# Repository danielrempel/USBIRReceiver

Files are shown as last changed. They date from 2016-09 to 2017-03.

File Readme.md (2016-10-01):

USBIRReceiver — an Atmega8L-based USB device to receive IR NEC commands from remote
control and configurable host software to run commands upon receiving
configured codes.

Device firmware is using Objective Development's V-USB (https://www.obdev.at/vusb/).
Host software uses Ben Hoyt's 'inih' library (https://github.com/benhoyt/inih).

Host software launches commands from its configuration file so it is
important to run the program from ordinary user. The user will need
rights to access the usb device.
I expect that adding a udev rule like this one:
> SUBSYSTEM=="usb", ATTR{idVendor}=="16c0", ATTR{idProduct}=="05dc", GROUP==<group>, MODE="0666"
will be enough.

Building:
* put usbdrv folder from OBdev's V-USB to the firmware folder without
	replacing the usbconfig.h file
* put Ben Hoyt's 'inih' library souces (ini.c,ini.h) to <project-root>/inih/
* firmware: cd firmware; make; make flash [; make fuse -- in case you need to re-fuse]
* host-side: cd host-side; make

NOTE: firmware's Makefile is configured to work with avrdude & USBAsp

NOTE: commands in ini file must not contain quoted spaces, up to 20 args

NOTE: repeat cmd from IR NEC is sent as 0xFA/0xFA by the receiver
		according to the standard it may be sent 104ms after the initial press
		from my experience it's not enough, so I just did code any reaction to it
		(on my remote a single click is constantly treated as a click + repeat)

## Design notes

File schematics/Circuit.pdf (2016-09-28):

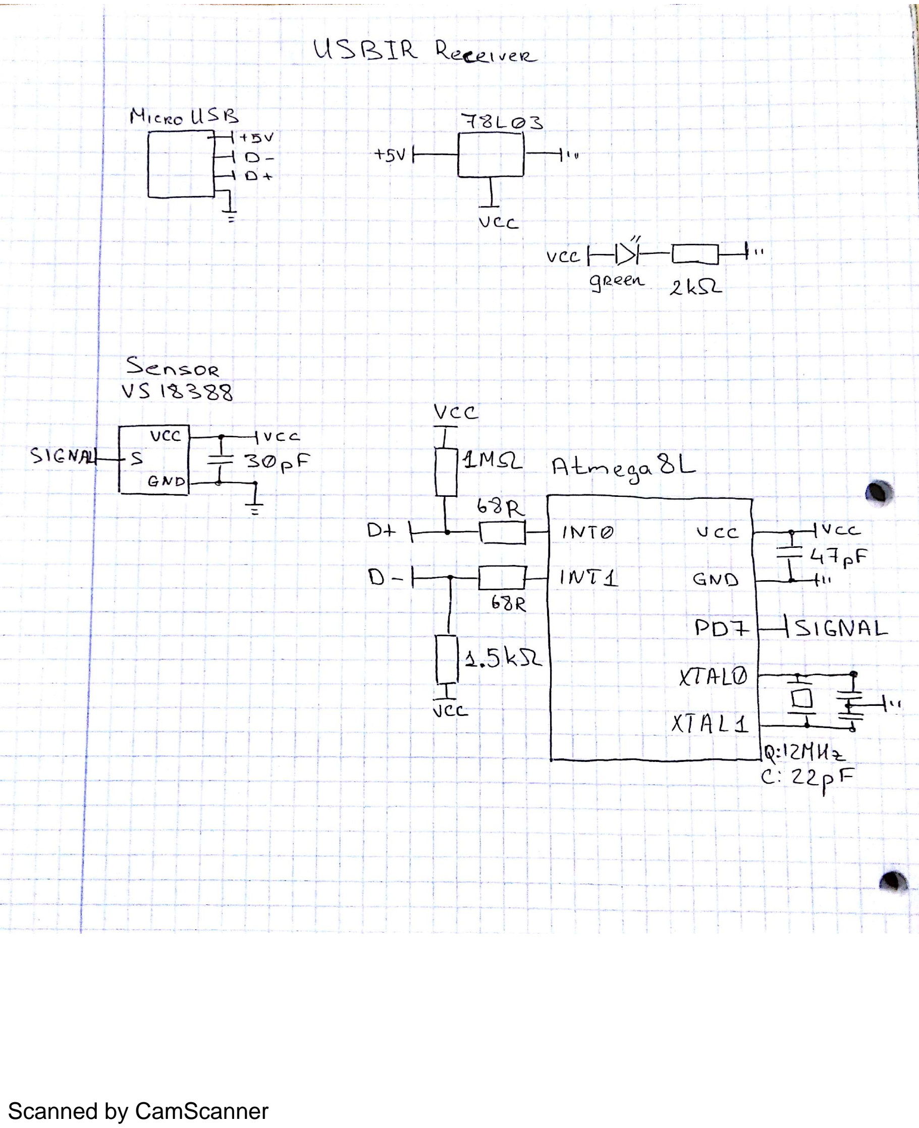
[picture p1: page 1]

Scanned by CamScanner

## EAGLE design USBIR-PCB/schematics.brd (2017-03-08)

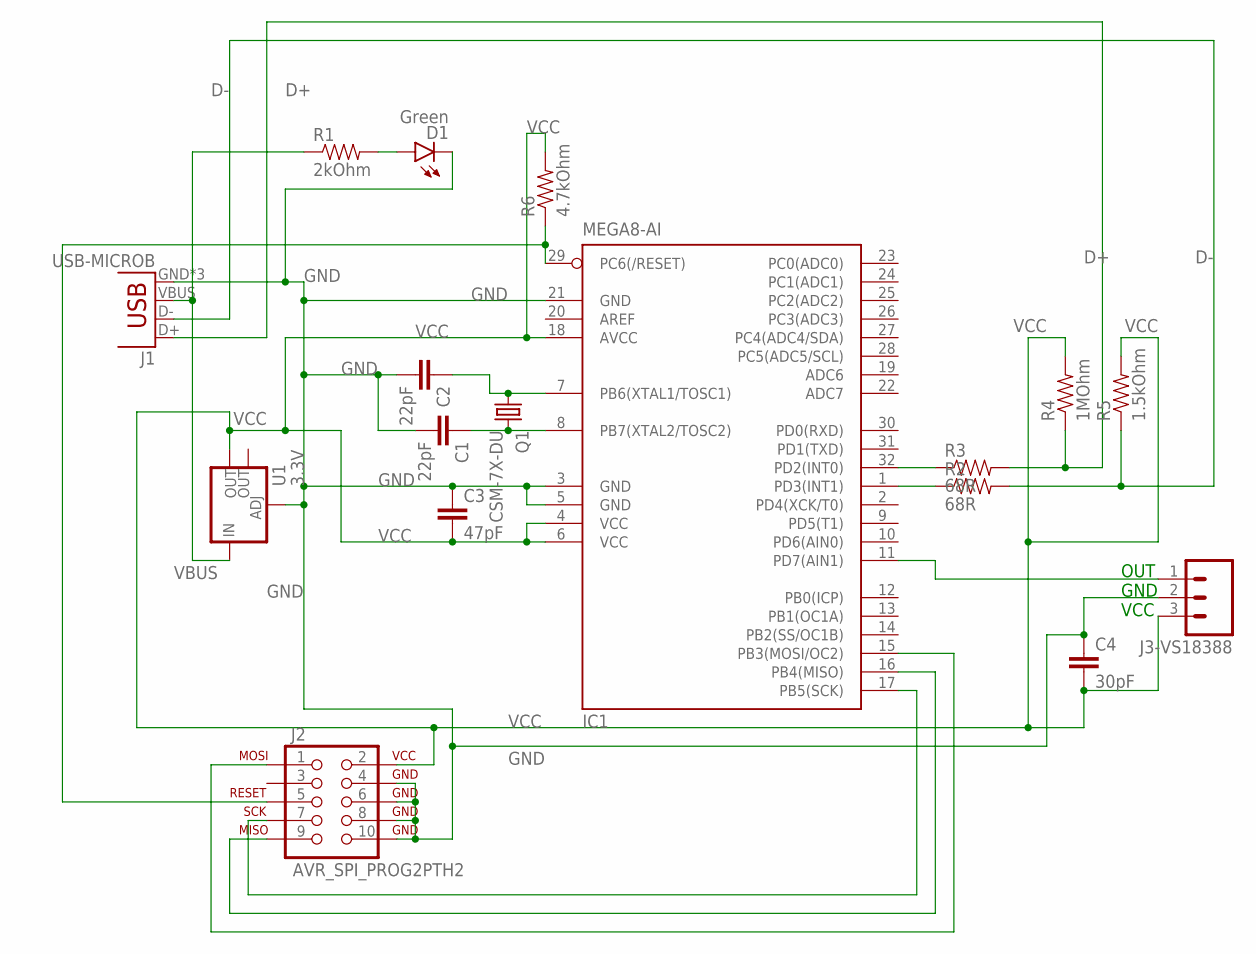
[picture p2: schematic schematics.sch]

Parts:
C1, C2: 22pF; 1206
C3: 47pF; 1206
C4: 30pF; 1206
D1: Green; LED-1206
IC1: MEGA8-AI; TQFP32-08
J1: USB-MICROB
J2: AVR_SPI_PROG2PTH2; 2X5-SHROUDED
J3-VS18388: M03PTH; 1X03
Q1: CSM-7X-DU
R1: 2kOhm; 1206
R2, R3: 68R; 1206
R4: 1MOhm; 1206
R5: 1.5kOhm; 1206
R6: 4.7kOhm; 1206
U1: 3.3V; SOT223

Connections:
D+: J1.D+, R3.2, R4.1
D-: J1.D-, R2.2, R5.1
GND: C1.2, C2.2, C3.1, C4.1, D1.C, IC1.3 (GND), IC1.5 (GND), IC1.21 (GND), J1.GND, J1.MT1 (GND), J1.MT2 (GND), J2.4 (GND), J2.6 (GND), J2.8 (GND), J2.10 (GND), J3-VS18388.2, U1.1 (ADJ)
unnamed: C1.1, IC1.8 (PB7(XTAL2/TOSC2)), Q1.2
unnamed: D1.A, R1.2
unnamed: C2.1, IC1.7 (PB6(XTAL1/TOSC1)), Q1.1
unnamed: IC1.11 (PD7(AIN1)), J3-VS18388.1
unnamed: IC1.16 (PB4(MISO)), J2.9 (MISO)
unnamed: IC1.17 (PB5(SCK)), J2.7 (SCK)
unnamed: IC1.15 (PB3(MOSI/OC2)), J2.1 (MOSI)
unnamed: IC1.29 (PC6(/RESET)), J2.5 (RESET), R6.1
unnamed: IC1.32 (PD2(INT0)), R3.1
unnamed: IC1.1 (PD3(INT1)), R2.1
VBUS: J1.VBUS, R1.1, U1.3 (IN)
VCC: C3.2, C4.2, IC1.4 (VCC), IC1.6 (VCC), IC1.18 (AVCC), J2.2 (VCC), J3-VS18388.3, R4.2, R5.2, R6.2, U1.2 (OUT)

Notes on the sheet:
OUT GND VCC

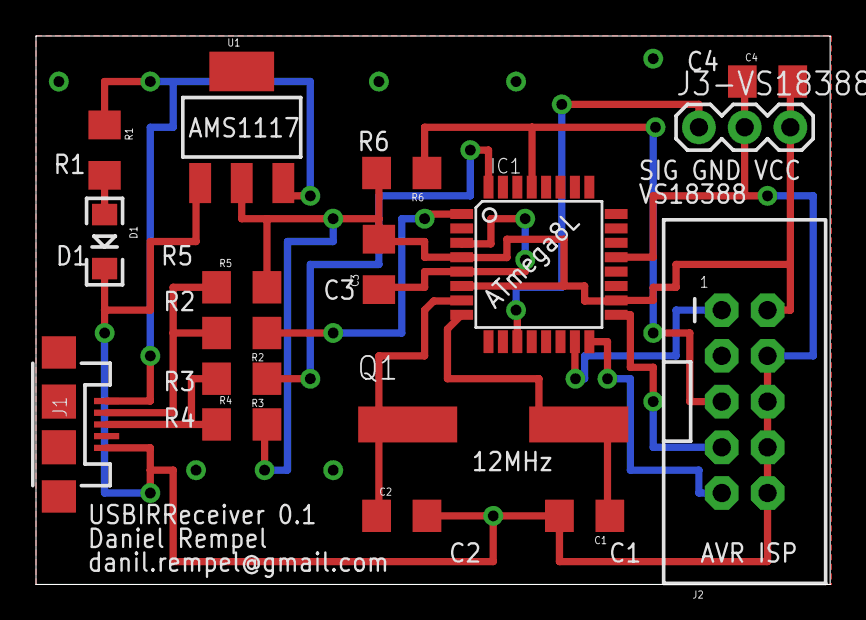
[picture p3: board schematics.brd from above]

Board: 2 copper layers, 44.1 x 30.5 mm, 17 parts (0 on the bottom side), 15 nets.

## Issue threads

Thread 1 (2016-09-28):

Stay silent upon interrupt transfer timeout

danielrempel, 2016-09-28:
Interrupt transfers are polled in blocking way with timeout of 10s and timeout error only means that user didn't touch the remote in last timeout period.

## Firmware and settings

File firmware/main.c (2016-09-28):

/* *********************************************************************
main.c from USBIRReceiver firmware
Copyright (C) 2016 Daniel Rempel <danil.rempel@gmail.com>

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
For full license text see License.txt
********************************************************************* */

// NOTE: the state machine may become stuck upon receiving non IR NEC signal
// TODO: ^^ reset the state machine's state to NONE 50-80 ms after the
//		initial pulse

#include "main.h"

#define SENSOR_STATE_PULSE					0
#define SENSOR_STATE_SPACE					1

// For state machine:
#define SIGNAL_STATE_NONE					0
#define SIGNAL_STATE_INIT_PULSE				1
#define SIGNAL_STATE_INIT_SPACE				2
#define SIGNAL_STATE_BIT_PULSE				3
#define SIGNAL_STATE_BIT_SPACE				4
#define SIGNAL_STATE_REPEATCMD_END_PULSE	5

// vv for prescaler /8
// vv = 3ms
#define MINIMAL_INIT_SPACE_LEN_IN_TIMER_CYCLES 4500
// vv = 0.7ms
#define MINIMAL_LOGICAL_ONE_SPACE_IN_TIMER_CYCLES 1350
// vv a bit less than 9ms
#define MINIMAL_INIT_PULSE_LEN_IN_TIMER_CYCLES 13500


// no commands are available.
USB_PUBLIC uchar usbFunctionSetup(uint8_t data[8]) {
	return 0;
}

uint8_t databuf[8];
uint8_t signalState = SIGNAL_STATE_NONE;
uint16_t timerValue = 0;
uint8_t bitCount = 0;

inline void stateMachine () {
	switch(signalState) {
	case SIGNAL_STATE_NONE:
		// noise-proofing: start counting the length of initial pulse
		TCNT1 = 0;
		// zero everything
		databuf[0] = 0;
		databuf[1] = 0;
		databuf[2] = 0;
		databuf[3] = 0;
		bitCount = 0;

		signalState = SIGNAL_STATE_INIT_PULSE;
		break;
	case SIGNAL_STATE_INIT_PULSE:
		// noise-proofing: initial pulse must be about 9ms
		if (TCNT1 < MINIMAL_INIT_PULSE_LEN_IN_TIMER_CYCLES) {
			// noise!
			signalState = SIGNAL_STATE_NONE;
		} else {
			TCNT1 = 0; // start measuring initial space length
			signalState = SIGNAL_STATE_INIT_SPACE;
		}
		break;
	case SIGNAL_STATE_INIT_SPACE:
		timerValue = TCNT1;
		// if space_len >= 3ms
		if (timerValue >= MINIMAL_INIT_SPACE_LEN_IN_TIMER_CYCLES) {
			// initial space is ordinary, next pulse is a part of a bit
			signalState = SIGNAL_STATE_BIT_PULSE;
		} else {
			// initial space is short — the commad is 'repeat'
			signalState = SIGNAL_STATE_REPEATCMD_END_PULSE;
		}
		break;
	case SIGNAL_STATE_BIT_PULSE:
		TCNT1=0;
		bitCount += 1;
		signalState = SIGNAL_STATE_BIT_SPACE;
		if(bitCount > 32) {
			signalState = SIGNAL_STATE_NONE;
		}
		break;
	case SIGNAL_STATE_BIT_SPACE:
		timerValue = TCNT1;
		// if space_len >= 0.7ms
		if (timerValue >= MINIMAL_LOGICAL_ONE_SPACE_IN_TIMER_CYCLES) {
		// ^^ we've got a logical 1; else do nothing
			SetBit(
				databuf[(bitCount-1) / 8], // I count bits from 1, processor
				(bitCount-1)%8				// counts them from 0
				);
		};

		// if we've already gathered all 32 bits — send the data
		if ((bitCount >= 32) && (usbInterruptIsReady())) {
			usbSetInterrupt(databuf, 8);
		}
		signalState = SIGNAL_STATE_BIT_PULSE;
		break;
	case SIGNAL_STATE_REPEATCMD_END_PULSE:
		// notify that we received a 'repeat' command from remote
		if( usbInterruptIsReady() ) {
			databuf[0] = 0xfa;
			databuf[1] = 0xaa;
			databuf[2] = 0xfa;
			databuf[3] = 0xaa;
			usbSetInterrupt(databuf, 8);
		}
		signalState = SIGNAL_STATE_NONE;
		break;
	}
}

int main() {

	PinIn(DDRD,7);
	PinLow(PORTD,7);

	uint8_t pulseState = SENSOR_STATE_SPACE;
	uint8_t prevPulseState = pulseState;
	uint8_t i;

	// enable 16-bit timer1
	// CS11 bit in TCCR1B means F_CPU/8 frequency for timer1
	SetBit(TCCR1B,1);
	TCNT1 = 0;

	// enable 1s watchdog timer:
    wdt_enable(WDTO_1S);
    usbInit();

	// enforce re-enumeration:
    usbDeviceDisconnect();
    for(i = 0; i<250; i+=1) {
        wdt_reset();
        _delay_ms(2);
    }
    usbDeviceConnect();

    sei();

    while(1) {
        wdt_reset();
        usbPoll();

        cli(); // the state machine code takes from 1.5 to 6 us
				// hope, that doesn't matter for V-USB :)
        // note: may be changed to pulseState = !GetPinHigh?
        if(GetPinHigh(PIND,7)) {
			pulseState = SENSOR_STATE_SPACE;
		}
		else {
			pulseState = SENSOR_STATE_PULSE;
		}

		if(pulseState != prevPulseState) {
			prevPulseState = pulseState;
			// state machine
			stateMachine();
		}
		sei();
    }

    return 0;
}

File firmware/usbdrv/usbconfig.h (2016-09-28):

/* Name: usbconfig.h
 * Project: V-USB, virtual USB port for Atmel's(r) AVR(r) microcontrollers
 * Author: Christian Starkjohann
 * Creation Date: 2005-04-01
 * Tabsize: 4
 * Copyright: (c) 2005 by OBJECTIVE DEVELOPMENT Software GmbH
 * License: GNU GPL v2 (see License.txt), GNU GPL v3 or proprietary (CommercialLicense.txt)
 */

#ifndef __usbconfig_h_included__
#define __usbconfig_h_included__

/*
General Description:
This file is an example configuration (with inline documentation) for the USB
driver. It configures V-USB for USB D+ connected to Port D bit 2 (which is
also hardware interrupt 0 on many devices) and USB D- to Port D bit 4. You may
wire the lines to any other port, as long as D+ is also wired to INT0 (or any
other hardware interrupt, as long as it is the highest level interrupt, see
section at the end of this file).
+ To create your own usbconfig.h file, copy this file to your project's
+ firmware source directory) and rename it to "usbconfig.h".
+ Then edit it accordingly.
*/

/* ---------------------------- Hardware Config ---------------------------- */

#define USB_CFG_IOPORTNAME      D
/* This is the port where the USB bus is connected. When you configure it to
 * "B", the registers PORTB, PINB and DDRB will be used.
 */
#define USB_CFG_DMINUS_BIT      3
/* This is the bit number in USB_CFG_IOPORT where the USB D- line is connected.
 * This may be any bit in the port.
 */
#define USB_CFG_DPLUS_BIT       2
/* This is the bit number in USB_CFG_IOPORT where the USB D+ line is connected.
 * This may be any bit in the port. Please note that D+ must also be connected
 * to interrupt pin INT0! [You can also use other interrupts, see section
 * "Optional MCU Description" below, or you can connect D- to the interrupt, as
 * it is required if you use the USB_COUNT_SOF feature. If you use D- for the
 * interrupt, the USB interrupt will also be triggered at Start-Of-Frame
 * markers every millisecond.]
 */
//define USB_CFG_CLOCK_KHZ       (F_CPU/1000)
#define USB_CFG_CLOCK_KHZ       12000
// Same thing but for sure. DANIEL
/* Clock rate of the AVR in kHz. Legal values are 12000, 12800, 15000, 16000,
 * 16500, 18000 and 20000. The 12.8 MHz and 16.5 MHz versions of the code
 * require no crystal, they tolerate +/- 1% deviation from the nominal
 * frequency. All other rates require a precision of 2000 ppm and thus a
 * crystal!
 * Since F_CPU should be defined to your actual clock rate anyway, you should
 * not need to modify this setting.
 */
#define USB_CFG_CHECK_CRC       0
/* Define this to 1 if you want that the driver checks integrity of incoming
 * data packets (CRC checks). CRC checks cost quite a bit of code size and are
 * currently only available for 18 MHz crystal clock. You must choose
 * USB_CFG_CLOCK_KHZ = 18000 if you enable this option.
 */

/* ----------------------- Optional Hardware Config ------------------------ */

/* #define USB_CFG_PULLUP_IOPORTNAME   D */
/* If you connect the 1.5k pullup resistor from D- to a port pin instead of
 * V+, you can connect and disconnect the device from firmware by calling
 * the macros usbDeviceConnect() and usbDeviceDisconnect() (see usbdrv.h).
 * This constant defines the port on which the pullup resistor is connected.
 */
/* #define USB_CFG_PULLUP_BIT          4 */
/* This constant defines the bit number in USB_CFG_PULLUP_IOPORT (defined
 * above) where the 1.5k pullup resistor is connected. See description
 * above for details.
 */

/* --------------------------- Functional Range ---------------------------- */
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

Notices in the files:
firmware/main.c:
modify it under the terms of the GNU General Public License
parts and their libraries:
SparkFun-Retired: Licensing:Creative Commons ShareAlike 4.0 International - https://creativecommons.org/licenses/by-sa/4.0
